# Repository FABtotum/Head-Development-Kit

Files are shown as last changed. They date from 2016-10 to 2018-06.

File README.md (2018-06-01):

Head Development Kit
====================

This repository contains various resources for the development of
add-on heads for the FABtotum. For general pointers on custom heads
development, see: http://www.fabtotum.com/head-development-guidelines.

**WARNING**: Firmware support for custom add-ons is not yet stable,
therefore actual implementation may change with respect to these
information without notice. If you get stuck on something not working
do [post an issue](/FABtotum/Head-Development-Kit/issues/new) to let us
know, or file a pull-request if you have a possible fix.

Checklist
---------

- **Get** the complete [Head Development Kit](https://store.fabtotum.com/intl/head-development-kit.html)
- **Print** the simple [HDB support](http://www.thingiverse.com/thing:1832391)
- Get **inspired** by example [sketches](Sketches)
- **Learn** from the detailed [documentation](Documentation)

Some more detail
--------------

### HDB simple support

You can self-print and make use of this barebone support for the HDB to
hack on your custom heads: http://www.thingiverse.com/thing:1832391

Source CAD models are available inside [HDB Support](/FABtotum/Head-Development-Kit/tree/master/HDB+Support), in
Autodesk Inventor (.ipt) and STEP (.stp) formats.

### Sketches

The [Sketches](Sketches) folder contains Arduino sketches that can be
run on a Arduino Nano or similar development board mounted on the
FABtotum Personal Fabricator through a HDB.

All sketches are tested to work with
[FAB-UI/Colibri](/FABtotum/fabui-colibri) and a recent version of
[FABlin](/FABtotum/FABlin) (version 1.1.0 or later). You can compile it
yourself from the [sources](/FABtotum/FABlin/tree/master) or pick one
of the [released](/FABtotum/FABlin/releases) hex images.

#### Sketches available:

- [**Dimmer**](https://github.com/FABtotum/Head-Development-Kit/tree/master/Sketches/Dimmer):
  A simple example that shows how to command led luminosity on an
  Arduino Nano mounted on the head slot through the HDB.
- [**Tester**](https://github.com/FABtotum/Head-Development-Kit/tree/master/Sketches/Tester):
  A more complete example that let you interactively debug IO and communication on the HDB (beware of 24Vdc lines though ;)
  With this sketch you'll be able to dynamically set IO pins' modes and levels. It is also able to setup a serial interface or a Two Wire interface.

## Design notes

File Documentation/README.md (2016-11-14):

FABtotum Head Development Kit
=============================

Documentation
-------------

Detailed documentation for custom developed head for the FABtotum is 
present in this repository's [wiki pages](../../../wiki).

In this folder you can find a useful cheatsheet with the essentials 
data and information for the Head Development Board.

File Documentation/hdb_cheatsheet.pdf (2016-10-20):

HDB | TOTUMduino
| | Vmax
++ 1/2/3 24VDC −− 4/5/6 | 2

+ 12 BLOWER − 13

+ 19 THERM − 20 | 67 TEMP_0

pin n.

4

5

HEAT − 8

PWM 9 SERVO +5V 10 | 11 SERVO0
+ | 7 | HEAT_0 | 2
| | | 4

5

I2C

SDA | 14 | 20 | SDA
SCL | 15 | 21 | SCL

ARDUINO

+ | 17
GND | 18

5VDC

+ 17
- 18

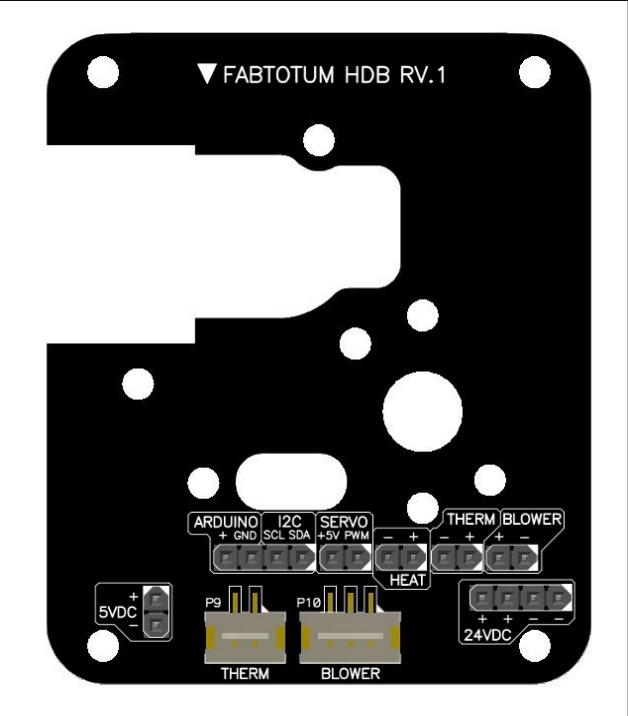
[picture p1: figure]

; Enable communication for head 0 (default head) M563 P0 S1

; Setup head serial interface
M575 P4 R<rx> T<tx> B<baud>

; Send one line of text to the head M790 P4 “text ...”

; Send multiple lines of text to the head M790 P4
text
⁝

Available serial parameters

<rx> | <tx> | <baud>
11 | 20 | 300
| 21 | 600
| 67* | 1200
67* | 11 | 2400
| 20 | 4800
| 21 | 9600

use these

* limited
bandwidth

14400
19200
28800
31250
38400
57600
115200

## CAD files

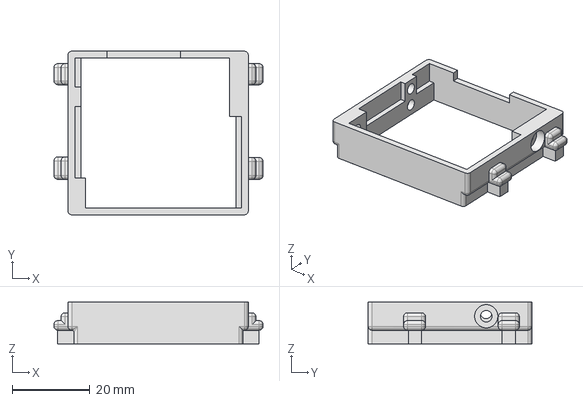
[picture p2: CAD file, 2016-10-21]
HDB Support/HDB Support.stp
53.9 x 42.2 x 10.8 mm

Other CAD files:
HDB Support/HDB Support.ipt

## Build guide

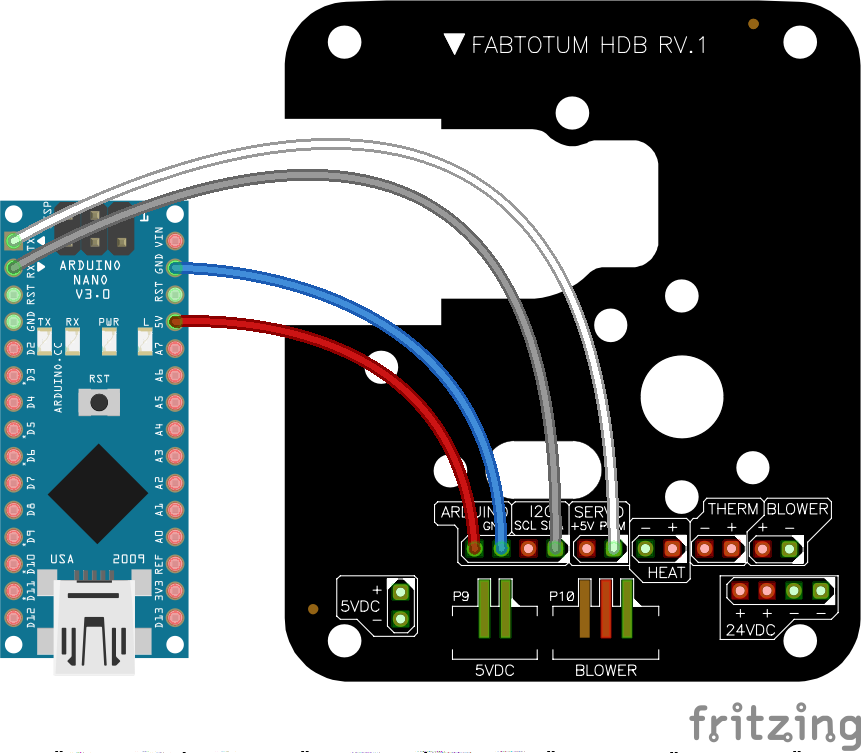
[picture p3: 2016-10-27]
Sketches/Dimmer/wiring.png

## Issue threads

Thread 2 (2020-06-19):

Looking for schematics

mgcrea, 2020-06-19:
Hey, I'm looking for the pinout of the existing head connector (which trace is fan/thermistor/hotend/etc.):

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

Looks like I could have guessed them from the published [Totemduino schematics](http://download.fabtotum.com/TOTUMduino%20schematics.PDF) but the link is now dead.

Any chance you would have the schematic file around?

NicolaiVdS, 2022-07-20:
https://web.archive.org/web/20171019133909/http://download.fabtotum.com/TOTUMduino%20schematics.PDF

hope this will help

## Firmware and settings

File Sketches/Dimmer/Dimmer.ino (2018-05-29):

/**
 * HDB Dimmer
 *
 * Implements a simple dimmer for the onboard led. Light intensity can be
 * commanded from the FABtotum Jog page.
 *
 * Compatible with:
 *
 *  Arduino Nano-like boards sporting an ATmega 168/328 microcontroller
 */

/**
 * Wiring
 *
 * See wiring.png for wiring diagram to an Arduino Nano v3
 *
 * Possible wirings (Nano <-> HDB <-> TOTUMduino) and corresponding
 * FABlin serial configuration parameters:
 *
 *  Nano    HDB
 * -------------
 *  +5V <-> ARDUINO +
 *  GND <-> ARDUINO GND
 *  RX0 <-> SDA <---.
 *  TX1 <-> PWM <-   \
 *                |   |
 *                v   v
 *      M575  P4 R11 T20 B...
 *
 *  Nano    HDB
 * -------------
 *  +5V <-> ARDUINO +
 *  GND <-> ARDUINO GND
 *  RX0 <-> SCL <---.
 *  TX1 <-> PWM <-   \
 *                |   |
 *                v   v
 *      M575  P4 R11 T21 B...
 */

/**
 * Steps to run:
 *
 * - Flash this sketch to your board and wire it to your HDB according to
 *   the diagrams above.
 *
 * - In FAB-UI's jog page enter the following commands:
 *
 *     M793 S0
 *
 *   These will disable the current head and temperature management
 *   for the default tool configuration
 *
 * - You can now physically uninstall the current head and swap it with
 *   the HDB in a safe way
 *
 * - Set a custom head id for your head, e.g.:
 *
 *     M793 S100
 *
 * - Enable communication for the default tool:
 *
 *     M563 P0 S1
 *
 * - Configure communication parameters
 *
 *     M575 P4 R<rx_pin> T<tx_pin> B<BAUDRATE>
 *
 *   where:
 *
 *     <rx_pin>, <tx_pin> depend on the Nano-HDB wiring (refer to Wiring)
 *     <BAUDRATE> is as #define'd later in this sketch (refer to Configuration)
 *
 * - Send a command:
 *
 *     M790 P4 "<cmd>"
 *
 *   where <cmd> is any of:
 *
 *     0-9 to set led's intensity
 *     +/- to increment/decrement led's intensity
 *
 *
 * Pro tip:
 *
 * In FAB-UI/Colibri, you can automate the above procedure by defining a custom head.
 */

/**
 * Configuration
 *
 * You can change the desired communication baudrate and customize your
 * led's pin number.
 *
 * Available baud rates:
 *
 *  300 600 1200 2400 4800 9600 14400 19200 28800 31250 38400 57600
 *
 * Suggested rates fall between 9600 and 38400.
 */

#define BAUDRATE 38400

#define LED 13


/*
 * You should not need to change the following, but if you do, it will switch from
 * the predefined hardware serial interface to the software serial library.
 */

#define sRX   0
#define sTX   1


/*
 * Sketch
 */

#include <Arduino.h>

#if (sRX != 0) || (sTX != 1)
   #include <SoftwareSerial.h>
   #define Main    softSerial
   #define Monitor Serial

   SoftwareSerial Main(sRX, sTX);
#else
   #define Main Serial
#endif

void setup ()
{
   pinMode(LED, OUTPUT);

   Main.begin(BAUDRATE);
#ifdef Monitor
   Monitor.begin(9600);
   Monitor.println("start");
#endif
}

void loop ()
{
   static uint8_t counter = 0;
   static uint8_t power   = 0;
   static char req[256] = "";
   static uint8_t q_i = 0;

   static uint8_t state = 1;

   if (counter == 0 && power > 0) {
      digitalWrite(LED,1);
   }

   if (counter++ > power) {
      digitalWrite(LED,0);
   }

   while (Main.available())
   {
      register unsigned char chin = Main.read();
#ifdef Monitor
      Monitor.write("rx ");
      Monitor.write(chin);
      Monitor.println("");
#endif
      switch (chin)
      {
         case '+':
            digitalWrite(LED,1);
            if (power < 240) {
               power += 16;
            } else {
               power = 255;
            } break;
         case '-':
            if (power >= 16) {
               power -= 16;
            } else {
               power = 0;
            } break;
         default:
            if (chin >= '0' && chin <= '9') {
               power = 28 * (chin - '0');
            }
      }

      Main.println(power);
   }
}

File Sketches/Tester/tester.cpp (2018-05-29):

#include "tester.h"
#include "gpio.h"
#include "serial.h"
#include "wire.h"

#include "Tester.ino"

#include <stdlib.h>     /* strtol */
#include <Arduino.h>

char* errmsg = 0;

lock_t serial_lock = 0;

bool acquire (lock_t &lock)
{
	lock_t pre = lock;
	lock++;
	pre++;
	if (pre == lock) {
		if (lock == 1) {
			return true;
		}
	}

	lock--;
	return false;
}

/*void release (lock_t &lock)
{
	lock--;
}*/

bool parse (const char *buffer)
{
	//Serial.print("Buffer: "); Serial.println(buffer);

	// Command prefix on the line
	char command[3] = "";
	// First argument (usually an IO pin)
	long int pin = 0;
	bool analog = false;
	// Remaining command string
	char *arg;

	// Next char is command (m: mode, r: read, w: write)
	strncpy(command, buffer, 2);

	// Then follows the pin number
	arg = buffer + 2;
	pin = strtol(arg, &arg, 10);

	// pin type is given by first char
	analog = (arg[0] == 'a')? true : false;

	arg++;

	if (analog) {
		pin = analogInputToDigitalPin(pin);
	}

	switch (command[0])
	{
		case 'a':
		case 'd':
		case 'p':
			return gpio_parse(command, pin, arg);

		case 's': return serial_parse(command, pin, arg);

		case 'w': return wire_parse(command, pin, arg);
	}
}

void setup ()
{
	Serial.begin(SERIAL_BAUDRATE);
	wait(serial_lock);
	Serial.println("start");
	release(serial_lock);
}

void loop ()
{
	static char buffer[15];
	static unsigned char bidx = 0;
	static unsigned value = 0;

	/*byte serial_bytes = 0;
	static char serial_buffer[16] = "";
	while (serial_available()) {
		serial_read();
		serial_bytes++;
	}
	if (serial_bytes) {
		wait(serial_lock);
		Serial.print("// Serial >> ");

		Serial.println(, HEX);
		release(serial_lock);
	}*/

	while (Serial.available())
	{
		char incr = Serial.read();
		if (bidx >= 14) bidx = 14;
		if (incr == '\n')
		{
			buffer[bidx++] = 0;
			bool ok = parse(buffer);
			bidx = 0;
			
			wait(serial_lock);
			if (ok) {
				Serial.println("ok");
			} else {
				Serial.print("!! ");
				if (errmsg) {
					Serial.println(errmsg);
					errmsg = 0;
				} else {
					Serial.println("");
				}
			}
			release(serial_lock);
		}
		else
		{
			buffer[bidx++] = incr;
		}
	}
}

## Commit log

2016-10-21 Added HDB Supoort CAD sources
    [HDB Support.ipt, HDB Support.stp]
2016-10-27 Added wiring diagram for Dimmer.
